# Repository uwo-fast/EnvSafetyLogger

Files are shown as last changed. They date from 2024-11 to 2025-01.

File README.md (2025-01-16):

# EnvSafetyLogger

An environmental monitoring system for industrial safety, featuring multi-gas sensors, temperature, humidity, data logging, and alerts.

This project involves designing an environmental safety monitor to measure and log air quality parameters. The monitor is housed in a custom 3D-printed enclosure and is built using a variety of sensors to measure gases and environmental conditions.

## Future Work

Future work includes:

- Weather-resistant enclosure (standard ingress protection)
- Wireless connectivity to enable data transmission and remote monitoring
- Improved calibration and integration of MQ sensors
  - See [CameronBrooks11/MQ-xx](https://github.com/CameronBrooks11/MQ-xx) for initial work involving extraction of regression parameters from component datasheets
- PCB design
- Variation for measuring closed systems with directed sampling
- Use Wet Bulb Globe Temperature (WBGT) as measure of heat stress conditions
  - WBGT is a measure of how hot it feels in direct sunlight, taking into account temperature, humidity, wind, and sun

## Results

### Schematic

The schematic shows the full circuit layout, including the Arduino Nano Every as the main controller, the various sensors, GUI components, and supporting circuitry. The schematic can be found in the `hardware` folder and is designed using KiCad.

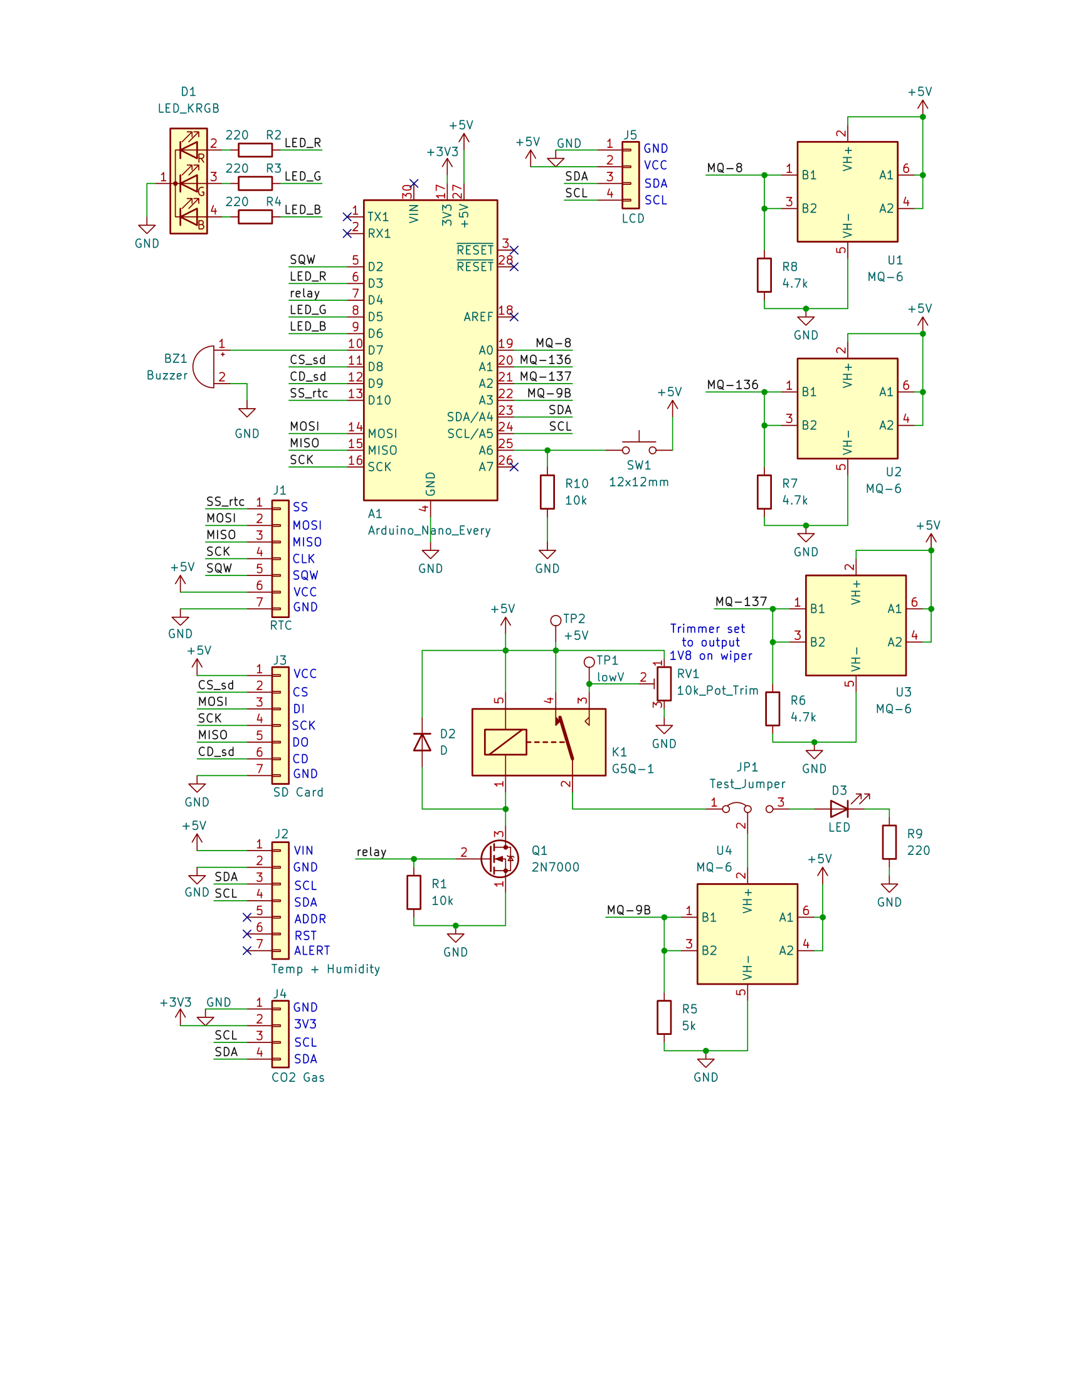
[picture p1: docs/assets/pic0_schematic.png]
Schematic


### Firmware and Hardware

The firmware for the EnvSafetyLogger is written in `.ino` format with configuration files in `.h` format, located in the `firmware` folder.

### 3D-Printed Enclosure

The enclosure was printed in PETG with a 0.8mm nozzle on a Prusa MK3S+, optimized to print without supports. The source file for the CAD design can be found [here on Onshape](https://cad.onshape.com/documents/19c4dfddea3c27460450ef2e/w/2ec8d1afb4664a197accd547/e/7aca4c51ab1e6bf835721462).

#### Fully Assembled Front View

Fully Assembled

#### Empty Enclosure

3D Printed Enclosure

### Sensor and Component Placement

This board includes the SCD41 for temperature, humidity, and carbon dioxide (CO₂); the ENS160 air quality sensor (AQI, TVOCs, eCO₂); various MQ-series gas sensors (MQ-8 for H₂, MQ-136 for H₂S, MQ-137 for NH₃, and MG-9B for CO and CH₄); and additional circuitry for driving the MQ sensor heaters, triggering audio-visual alarms, logging timestamped data, and displaying information. The board is constructed to be modular and serviceable while still being mechanically rigid and reliable, using headers and standoffs for all components.

#### Sensor Components Mounted

Sensors Populated

#### GUI and Control Panel Mounted

GUI Populated

### Soldered Boards

Two views of the soldered board showing component placement and wiring.

#### Soldered Front View

Soldered Front 1
Soldered Front 2

### Calibration and Testing

Testing and tuning were performed to ensure accurate sensor readings. The MQ9B sensor, which detects CO and CH₄, requires a bi-voltage heater cycling to operate correctly, switching between low and high voltages to improve sensitivity and response time. A trimmer pot on the board is tuned to set the relay's NO (normally open) output to 1.5V, which is used to control the heater cycle. Headers are provided to facilitate testing and allow for disconnecting the line to the MQ9B heater pin. This setup enables switching to an LED for testing without affecting the MQ9B sensor, making it easier to validate heater operation independently.

Future work will focus on establishing standard calibration procedures, including regression curve fitting of the sensor's analog signal to match the expected ppm range, and compensating this fitted curve for environmental factors such as temperature and humidity to improve accuracy.

#### Voltage Tuning

Voltage Tuning

### Installed in Environment

Once assembled, the monitor was installed and tested in a mobile photovoltaic (PV) box used for electrolysis experiments on wastewater.

Installed

### License

This project is licensed under the GNU General Public License v3.0 (GPL-3.0). See the `LICENSE` file for details.

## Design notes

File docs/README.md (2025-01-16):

# Docs

_EnvSafetyMonitor - Environmental Safety Monitoring System_

The [`assets`](assets/) folder contains images related to design and build; [`datasheets`](mq-datasheets/) contains datasheets for hardware components used in the build.

## Table of Contents

- [Docs](#docs)
  - [Table of Contents](#table-of-contents)
  - [Introduction](#introduction)
  - [System Overview](#system-overview)
  - [Hardware Components](#hardware-components)
  - [Software Dependancies](#software-dependancies)
  - [Usage Instructions](#usage-instructions)
  - [Troubleshooting](#troubleshooting)

## Introduction

EnvSafetyMonitor is an Environmental Safety Monitoring System designed to continuously monitor various environmental parameters to ensure safety and compliance. The system leverages multiple sensors to detect levels of gases, temperature, and humidity, providing real-time data visualization, logging, and alarm notifications.

## System Overview

The system integrates several components:

- **Sensors:** SCD41 (CO₂, temperature, humidity), ENS160 (AQI, TVOC, eCO₂), MQ series (H₂, H₂S, NH₃, CH₄, CO).
- **Display:** 2x16 I2C LCD for real-time data visualization.
- **Data Logging:** SD card module for recording sensor data in CSV format.
- **Alarms:** Buzzer and RGB LED indicators for alerting based on predefined thresholds.
- **User Interface:** Push button to navigate through different data screens on the LCD.

## Hardware Components

- **Arduino Nano:** The microcontroller that orchestrates all operations.
- **SCD41 Sensor:** Measures CO₂ concentration, temperature, and humidity.
- **ENS160 Sensor:** Provides Air Quality Index (AQI), Total Volatile Organic Compounds (TVOC), and equivalent CO₂ (eCO₂) readings.
- **MQ Series Sensors:**
  - **MQ-8:** Detects Hydrogen (H₂) concentrations.
  - **MQ-136:** Measures Hydrogen Sulfide (H₂S) levels.
  - **MQ-137:** Monitors Ammonia (NH₃) concentrations.
  - **MQ-9b:** Detects Methane (CH₄) and Carbon Monoxide (CO) levels.
- **2x16 I2C LCD:** Displays sensor readings and system status.
- **SD Card Module:** Logs sensor data for future analysis.
- **RGB LEDs:** Visual indicators for system status (Green for normal, Red for alarms).
- **Piezo Buzzer:** Auditory alarm for threshold breaches.
- **Relay Module:** Controls the heating element for the MQ-9b sensor.
- **Push Button:** Allows users to navigate through LCD screens.
- **RTC Module (DS3234):** Keeps accurate time for timestamping logs.

## Software Dependancies

Consult the following table for the various library dependancies.

| Dependency | Source |
| --- | --- |
| [SPI](https://www.arduino.cc/en/Reference/SPI) | Included by default in the Arduino IDE |
| [Wire](https://www.arduino.cc/en/Reference/Wire) | Included by default in the Arduino IDE |
| [EEPROM](https://www.arduino.cc/en/Reference/EEPROM) | Included by default in the Arduino IDE |
| [Math.h](https://www.arduino.cc/reference/en/language/functions/math/) | Included by default in the Arduino IDE |
| [SD](https://www.arduino.cc/en/Reference/SD) | Search `SD` in Lib Manager |
| [Rtc (Makuna)](https://github.com/Makuna/Rtc) | Search `rtc makuna` in Lib Manager |
| [SparkFun_SCD4x_Arduino_Library](https://github.com/sparkfun/SparkFun_SCD4x_Arduino_Library) | Search `SparkFun SCD4x` in Lib Manager |
| [ScioSense_ENS160](https://github.com/adafruit/ENS160_driver) | Search `Adafruit ENS160` in Lib Manager |
| [MQSensorsLib](https://github.com/miguel5612/MQSensorsLib) | Search `mqunified` in Lib Manager |
| [LiquidCrystal_I2C](https://github.com/johnrickman/LiquidCrystal_I2C) | Search `LiquidCrystal I2C Frank` in Lib Manager |
| [LiquidMenu](https://github.com/VasilKalchev/LiquidMenu) | Search `LiquidMenu` in Lib Manager |

## Usage Instructions

1. **Setup Hardware:**

   - Connect all sensors to their respective pins as defined in `config.h`.
   - Ensure the SD card is properly inserted into the SD card module.
   - Connect the RTC module to the designated chip-select pin.
   - Attach the RGB LEDs, buzzer, and relay to their respective pins.
   - Connect the push button to `A6` with appropriate pull-up/down resistors.

2. **Configure Software:**

   - Adjust settings in `config.h` as needed, such as enabling/disabling debug prints, calibration, and data logging.
   - Set appropriate threshold values for each sensor based on environmental safety requirements.

3. **Calibration:**

   - If `PERFORM_MQ_CALIBRATION` is set to `true`, calibrate the MQ sensors in clean air conditions to establish baseline readings.
   - After calibration, set `PERFORM_MQ_CALIBRATION` to `false` to use the stored R0 values from EEPROM.

4. **Running the System:**

   - Upload the `main.ino` sketch to the Arduino Nano.
   - Upon startup, the system initializes all components and begins monitoring.
   - Navigate through different sensor data screens using the push button.
   - Monitor alarms via the buzzer and RGB LED indicators.

5. **Data Access:**
   - Retrieve the `dataLog.csv` file from the SD card for analysis using spreadsheet software or other data processing tools.
   - Real-time data can be viewed via Serial Monitor if enabled.

## Troubleshooting

- **SD Card Initialization Failed:**

  - Ensure the SD card is properly inserted.
  - Verify the chip-select pin is correctly connected.
  - Check the SD card format (should be FAT16/FAT32).

- **RTC Lost Confidence in DateTime:**

  - Check RTC module connections.
  - Ensure the RTC has a backup battery for maintaining time.

- **Sensor Not Detected:**

  - Verify wiring connections for each sensor.
  - Ensure sensors are powered correctly.
  - Check for I2C address conflicts.

- **Alarms Not Triggering:**

  - Confirm that sensor readings exceed the set thresholds.
  - Ensure the buzzer and LED pins are correctly connected and functioning.

- **LCD Not Displaying Data:**
  - Ensure the LiquidMenu library is correctly configured
    - Ensure you have modified the LiquidMenu library header to use the I2C library
    - Ensure the I2C LCD library is also installed and included in the project
  - Verify I2C connections.
  - Check the LCD address and dimensions in `config.h`.

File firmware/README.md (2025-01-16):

# Firmware Docs

Welcome to the firmware docs! Here you will find...fuinish

## Software Structure

The software is divided into four main files:`main.ino`, `config.h`, `mqGas.h` and `alarmThresholds.h`.

### `main.ino`

The program monitors environmental safety parameters using various sensors and logs data to an SD card and serial output.

#### Program Flow

1. Initialize pins, sensors, and libraries
2. Read sensor data every `SAMPLING_INTERVAL_MS`
3. Update LCD menu display and check/triggers alarms
4. Log data to SD card and serial output

#### Key Components

- **Sensor Initialization and Calibration**:
  - SCD41: Begins periodic measurement upon successful initialization
  - ENS160: Configured to operate in standard mode
  - MQ Series: Calibrated using `PERFORM_MQ_CALIBRATION` flag, analog values mapped to ppm using exponential regression, R0 value stored in EEPROM
- **Alarm System**:
  - Threshold-based alarm triggering (DANGER/WARNING)
  - Activates piezo buzzer and changes RGB LED color to red upon alarm
- **Logging**:
  - SD card (CSV): Records sensor data with timestamp
  - Serial output (JSON): Real-time monitoring or integration with other systems
- **LCD Menu Interface**:
  - Utilizes LiquidMenu library for multiple screens displaying sensor readings
  - Navigation via push button, with screens for system title, timestamp, and individual sensor readings

### `config.h`

This header file contains all configurable settings, pin definitions, thresholds, and other constants used throughout the EnvSafetyMonitor system.

- Debugging Settings
  - `ENABLE_DEBUG_PRINTS`: Toggle for enabling/disabling debug messages.
  - `ENABLE_DATA_PRINTS`: Toggle for enabling/disabling data output to Serial.
- Calibration Settings
  - `PERFORM_MQ_CALIBRATION`: Determines whether to calibrate MQ sensors on startup. Note that once this is enabled you should boot the system, allow calibration, then reupload with this setting disabled during production use.
- Logging Settings
  - `LOG_FILE_NAME`: Name of the CSV log file on the SD card.
  - `LOG_TO_SD`: Enables/disables logging sensor data to the SD card.
- Standard Colors Definitions
  - `RED`: RGB values for red color.
  - `GREEN`: RGB values for green color.
- Sampling Settings
  - `SAMPLING_INTERVAL_MS`: Time interval between consecutive sensor readings.
- I2C LCD Settings
  - `LCD_I2C_ADDRESS`: I2C address of the LCD.
  - `LCD_COLUMNS`: Number of columns on the LCD.
  - `LCD_ROWS`: Number of rows on the LCD.
- Serial Communication Settings
  - `SERIAL_BAUD_RATE`: Baud rate for Serial communication.
- Debounce Settings
  - `DEBOUNCE_DELAY_MS`: Delay for debouncing the push button.

### `alarmThresholds.h`

The following thresholds are used to trigger warning and danger alarms for various environmental parameters.

#### Temperature & Humidity Thresholds

- Temperature
  - `TEMP_WARNING_THRESHOLD_C`: 30.0°C - Temperature warning threshold
  - `TEMP_DANGER_THRESHOLD_C`: 35.0°C - Temperature danger threshold
  - Temperatures around 30°C increase the risk of heat stress, while temperatures at or above 35°C pose a higher risk of heat-related illnesses.
- Relative Humidity (RH)
  - `HUMIDITY_WARNING_THRESHOLD_RH`: 60.0%RH - Humidity warning threshold
  - `HUMIDITY_DANGER_THRESHOLD_RH`: 80.0%RH - Humidity danger threshold
    High humidity levels reduce the body's ability to cool itself, with increased risk at 80% humidity.

#### Gas Concentration Thresholds

- Carbon Dioxide (CO2)

  - `CO2_WARNING_THRESHOLD_PPM`: 5000 ppm - CO₂ warning threshold
  - `CO2_DANGER_THRESHOLD_PPM`: 15000 ppm - CO₂ danger threshold
  - **Based on:** OSHA's PEL for CO₂ is 5,000 ppm over an 8-hour workday, with concentrations above 15,000 ppm causing respiratory issues.

- Hydrogen (H2)

  - `H2_WARNING_THRESHOLD_PPM`: 4000 ppm - H₂ warning threshold
  - `H2_DANGER_THRESHOLD_PPM`: 8000 ppm - H₂ danger threshold
  - **Based on:** Hydrogen is highly flammable, with warning and danger thresholds set at 10% and 20% of the Lower Explosive Limit (LEL).

- Hydrogen Sulfide (H2S)

  - `H2S_WARNING_THRESHOLD_PPM`: 10 ppm - H₂S warning threshold
  - `H2S_DANGER_THRESHOLD_PPM`: 50 ppm - H₂S danger threshold
  - **Based on:** OSHA's PEL for H₂S is 10 ppm over an 8-hour workday, with concentrations above 15 ppm causing eye irritation.

- Ammonia (NH3)

  - `NH3_WARNING_THRESHOLD_PPM`: 25 ppm - NH₃ warning threshold
  - `NH3_DANGER_THRESHOLD_PPM`: 50 ppm - NH₃ danger threshold
  - **Based on:** OSHA's PEL for ammonia is 50 ppm and 25 ppm over an 8-hour workday, with levels above 50 ppm causing eye and respiratory irritation.

- Methane (CH4)

  - `CH4_WARNING_THRESHOLD_PPM`: 5000 ppm - CH₄ warning threshold
  - `CH4_DANGER_THRESHOLD_PPM`: 10000 ppm - CH₄ danger threshold
  - **Based on:** Methane is flammable, with warning and danger thresholds set at 10% and 20% of the Lower Explosive Limit (LEL).

- Carbon Monoxide (CO)
  - `CO_WARNING_THRESHOLD_PPM`: 35 ppm - CO warning threshold
  - `CO_DANGER_THRESHOLD_PPM`: 50 ppm - CO danger threshold
  - **Based on:** OSHA's PEL for CO is 50 ppm and 25 ppm over an 8-hour workday, with levels above 50 ppm causing headaches and dizziness.

### `mqgas.h`

The MQ gas sensors detect specific gases by measuring the change in their internal resistance when exposed to different gas concentrations. The resistance value (`RS`) changes in proportion to the gas concentration, allowing for the calculation of the gas's parts per million (ppm) level.

#### Regression Formula

The MQ sensors use a logarithmic formula to relate the sensor resistance ratio (`RS / R0`) to gas concentration:

```c
ppm = a * (RS / R0)^b
```

where:

- a and b are constants specific to each sensor and gas, derived from calibration and datasheet values.
- RS is the sensor resistance in the current environment.
- R0 is the baseline resistance of the sensor in clean air, obtained through calibration.

#### Sensor Resistance (RS) Calculation

RS is calculated from the sensor's analog voltage reading as follows:

```c
RS = ((V_supply - V_sensor) \* RL) / V_sensor
```

where:

- V_sensor is the voltage at the sensor’s output.
- V_supply is the supply voltage to the sensor.
- RL is the load resistance in series with the sensor.

#### Baseline Resistance (R0) Calibration

R0 represents the sensor’s resistance in a known clean air environment and is used as a baseline for gas concentration calculations. During calibration:

- The sensor's RS is measured in clean air.
- R0 is calculated as the average RS in this environment and is saved in EEPROM to maintain consistency across power cycles.

#### Clean Air Ratio

The clean air ratio (RS / R0 in clean air) is a reference value specific to each sensor. This ratio helps establish the baseline resistance and is used during R0 calibration.

#### Sensor Definitions

- **MQ-8 Sensor (Hydrogen, H₂)**

  - `MQ8_TYPE`: "MQ-8"
  - `MQ8_RATIO_CLEAN_AIR`: 70
  - `A_VALUE_MQ8`: 71.7592
  - `B_VALUE_MQ8`: -0.9760
  - `EEPROM_ADDRESS_MQ8_R0`: 0

- **MQ-136 Sensor (Hydrogen Sulfide, H₂S)**

  - `MQ136_TYPE`: "MQ-136"
  - `MQ136_RATIO_CLEAN_AIR`: 3.6
  - `A_VALUE_MQ136`: 1.0715
  - `B_VALUE_MQ136`: -0.8877
  - `EEPROM_ADDRESS_MQ136_R0`: 4

- **MQ-137 Sensor (Ammonia, NH₃)**

  - `MQ137_TYPE`: "MQ-137"
  - `MQ137_RATIO_CLEAN_AIR`: 4.2
  - `A_VALUE_MQ137`: 1.0613
  - `B_VALUE_MQ137`: -0.8905
  - `EEPROM_ADDRESS_MQ137_R0`: 8

- **MQ-9b Sensor (Carbon Monoxide, CO & Methane, CH₄)**
  - `MQ9B_TYPE`: "MQ-9"
  - `MQ9B_RATIO_CLEAN_AIR`: 9.6
  - `A_VALUE_MQ9B_CH4`: 4.9059
  - `B_VALUE_MQ9B_CH4`: -0.6699
  - `A_VALUE_MQ9B_CO`: 4.8726
  - `B_VALUE_MQ9B_CO`: -0.6989
  - `EEPROM_ADDRESS_MQ9B_R0`: 12
  - `SETTLE_TIME_TO_CO`: 20000 ms
  - `SETTLE_TIME_TO_CH4`: 10000 ms

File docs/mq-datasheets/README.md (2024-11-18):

# MQ Gas Sensors Overview

MQ gas sensors, such as the MQ-8, are low-cost, widely used sensors that detect various gases by measuring the change in conductivity of a SnO2-sensitive material in response to gas concentration. This change in conductivity can be interpreted as a resistance change (Rs), which increases or decreases depending on the target gas.

## Sensor Operation and Calibration

1. **Structure and Operation**:
   - MQ sensors consist of a heating element and a SnO2-sensitive layer. The sensor requires two voltage inputs: a heater voltage (VH) to maintain the sensor's optimal temperature and a circuit voltage (VC) for measurement.
   - In clean air, the sensor's resistance (Rs) is at a baseline level, and the sensor outputs a corresponding voltage (VRL) across an external load resistor (RL). When exposed to a target gas, the conductivity increases, causing Rs to change based on the gas concentration.

2. **Calibration**:
   - Each sensor requires calibration to determine its baseline resistance, R0, which represents the resistance in clean air. Calibration steps:
     - Expose the sensor to clean air and measure Rs.
     - Calculate R0 using the clean air ratio, a predefined constant (e.g., MQ-8 clean air ratio is 70), as follows:
       R0 = Rs / Clean Air Ratio
   - This value of R0 is unique to each sensor and serves as a reference for future measurements.

3. **Using R0 for Gas Measurement**:
   - During operation, Rs is measured in the presence of the target gas, and the Rs/R0 ratio is calculated. This ratio can be used with a regression equation derived from the sensor’s datasheet to estimate gas concentration (PPM).
   - The general form of the regression equation is:
     PPM = A * (Rs / R0) ^ B
     where A and B are gas-specific constants provided by the datasheet or determined experimentally.

4. **Typical Sensitivity and Environment Effects**:
   - MQ sensors are sensitive to various gases, but their sensitivity varies depending on the gas. For example, the MQ-8 is primarily sensitive to hydrogen but also responds to gases like methane (CH4) and carbon monoxide (CO) to a lesser extent.
   - Temperature and humidity changes can affect Rs, so periodic recalibration or compensation may be necessary for consistent results, especially in variable environments.

## Important Parameters

- **Clean Air Ratio**: A predefined constant that indicates the expected Rs/R0 ratio in clean air.
- **R0**: The baseline sensor resistance in clean air, determined during calibration.
- **Rs**: The sensor resistance measured in the presence of a target gas.
- **A and B Constants**: Regression constants used to calculate gas concentration based on Rs/R0.

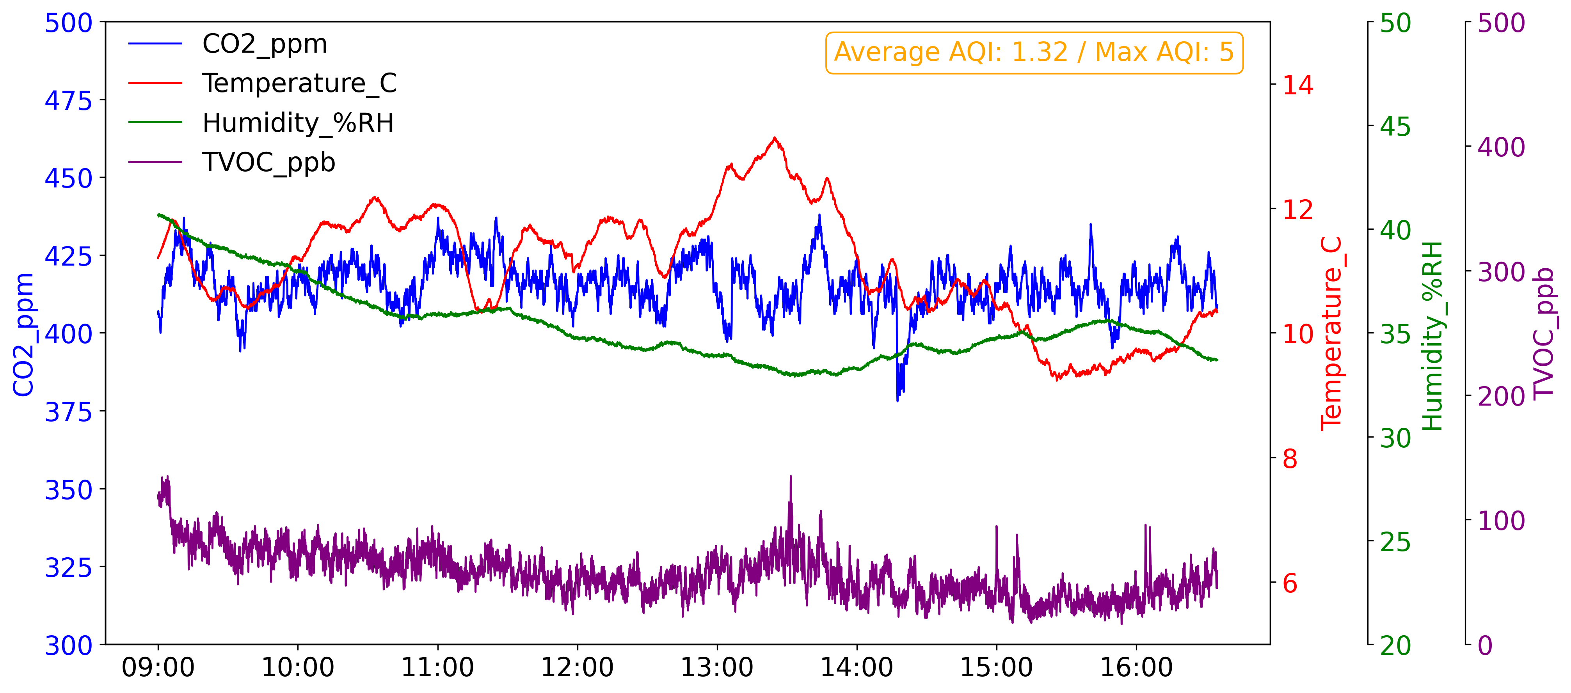
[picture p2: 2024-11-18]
docs/data_analysis_11072024/environment_data_notitle.png

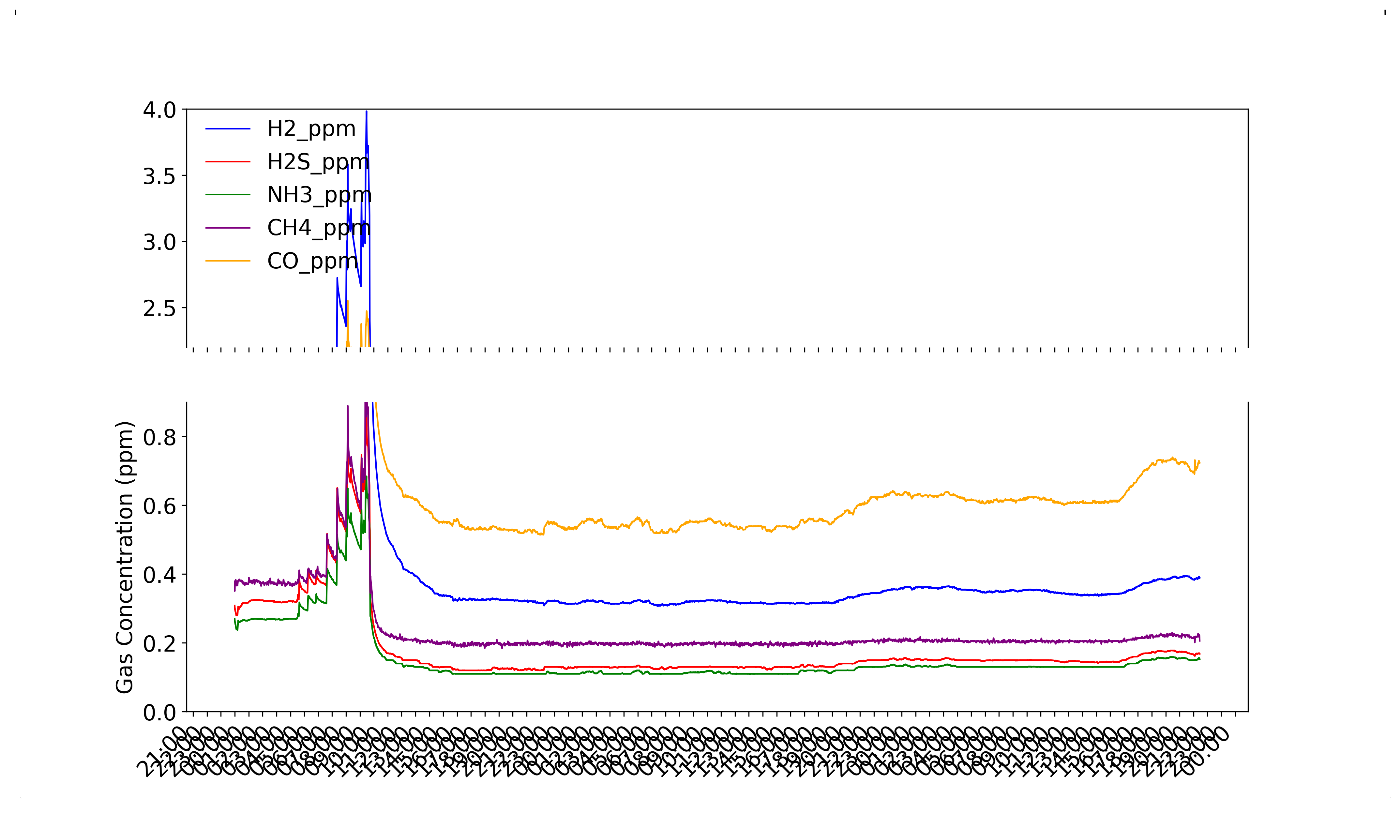
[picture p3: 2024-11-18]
docs/data_analysis_11072024/newData/gas_concentrations_smoothed_notitle3.png

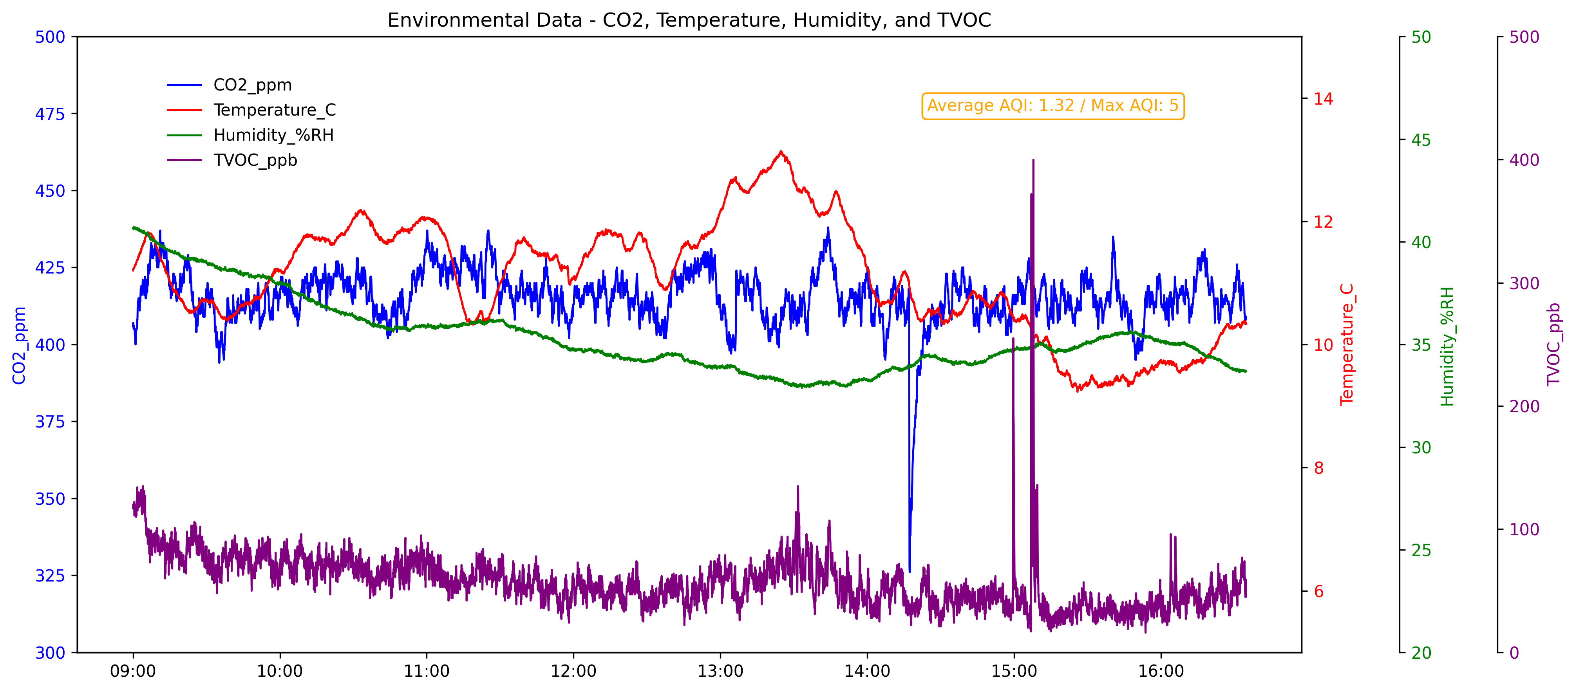
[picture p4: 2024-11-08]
docs/data_analysis_11072024/environment_data.png

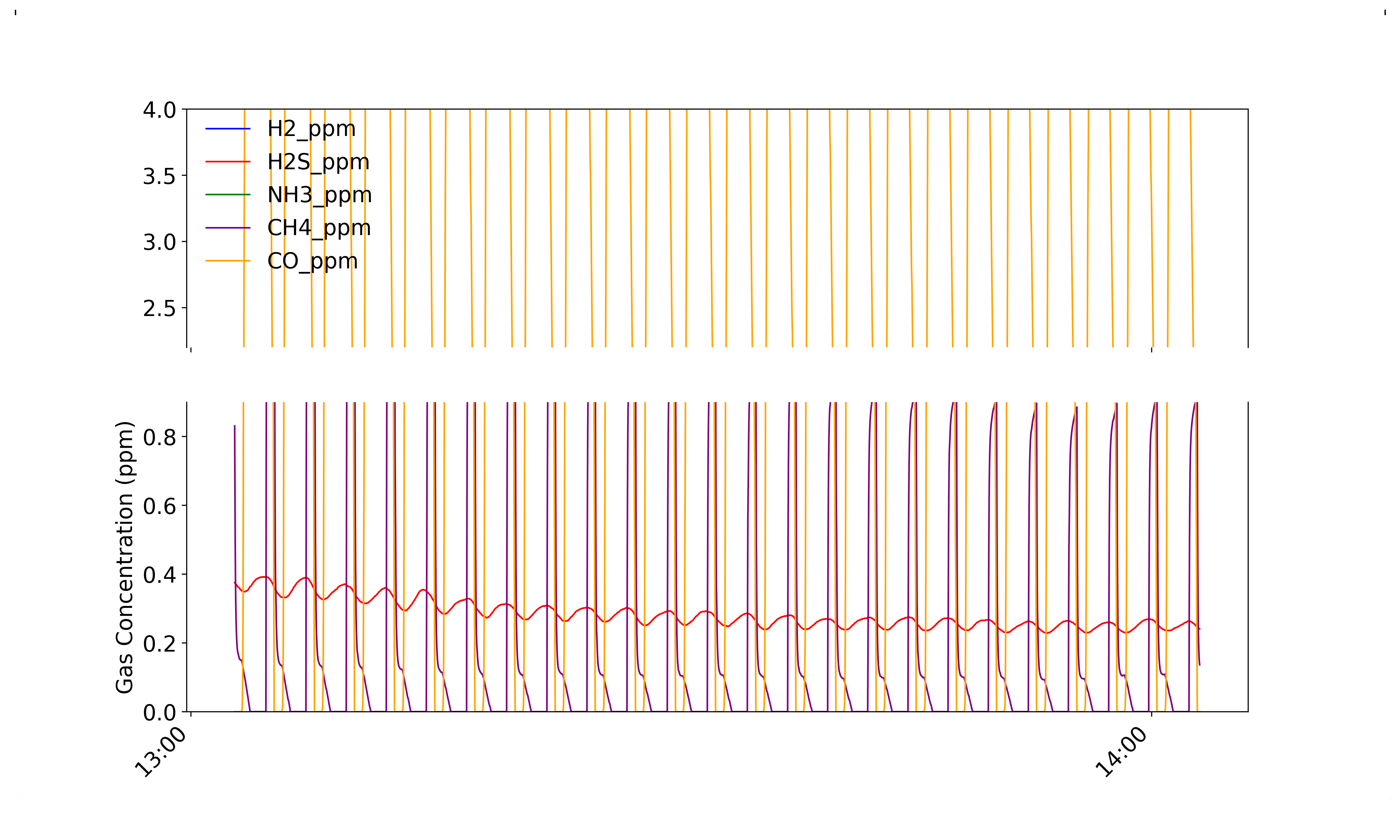
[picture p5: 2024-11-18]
docs/data_analysis_11072024/gas_concentrations_smoothed_notitle.png

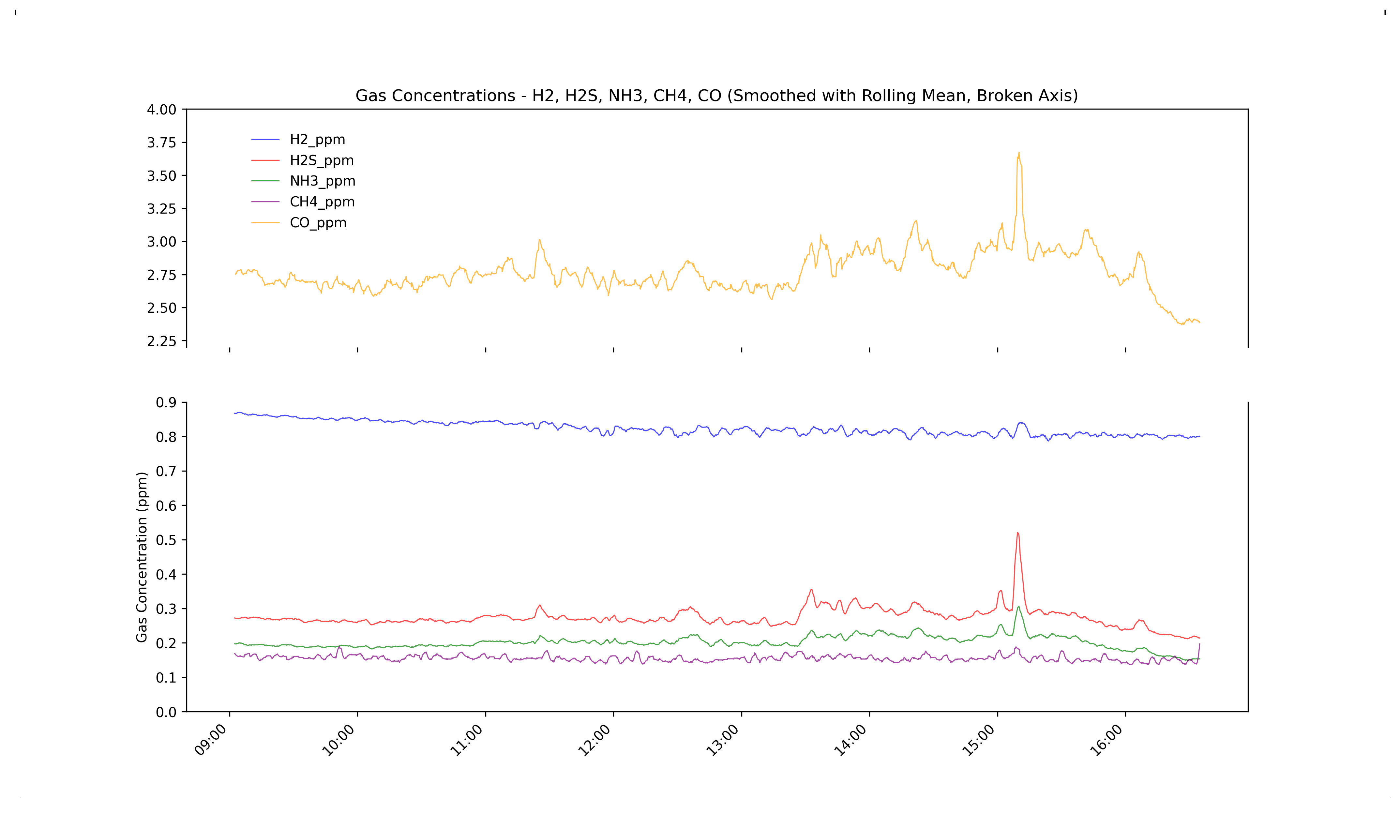
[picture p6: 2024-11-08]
docs/data_analysis_11072024/gas_concentrations_smoothed.png

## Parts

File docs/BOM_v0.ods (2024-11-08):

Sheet: Sheet1
Name | Description | Quantity | Cost | Link | Notes
Arduino Nano Every | Controller | 1 |  | mouser
Sparkfun dead on DS3231 |  | 1 |  | sparkfun
Sparkfun Level Shifting MicroSD |  | 1 |  | sparkfun
32GB Micro SD |  | 1
CO2 sensor sparkfun SCD41 |  | 1 |  | sparkfun
Adafruit ENS160 |  | 1 |  | adafruit
MQ-8 |  | 1 |  | sparkfun
MQ-136 |  | 1 |  | sparkfun
MQ-137 |  | 1 |  | sparkfun
MQ-9B |  | 1 |  | sparkfun
MQ Breakout |  | 4 |  | sparkfun
5mm RGB common cathode LED |  | 1
5mm LED |  | 1
Piezo Buzzer 5v |  | 1
Push button |  | 1
LCD I2C 2x16 |  | 1 |  | amazon sunfounder i2c lcd
10k Trim Pot |  | 1
5k Resistor |  | 4
220 Resistor |  | 4
mosfet 2n7000 |  | 1
10k Resistor |  | 2
1n4148 Diode

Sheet: Sheet2
Part # | Name | Quantity | Cost (CAD) | Total Cost (CAD) | Link | Notes
1 | Arduino Nano Every | 1.00 | $17.99 | $17.99 | https://www.canadarobotix.com/products/2495 | Bigger memory than classic Nano with 328P, available in Canada
2 | SparkFun DeadOn RTC Breakout - DS3234 | 1.00 | $34.09 | $34.09 | https://www.sparkfun.com/products/10160 | Accurate SPI RTC
3 | SparkFun Level Shifting microSD Breakout | 1.00 | $8.28 | $8.28 | https://www.sparkfun.com/products/13743 | Handles 3.3V/5V logic levels
4 | 32GB MicroSD Card | 1.00 | $12.99 | $12.99 | https://a.co/d/8i0q3gs | Compatible with microSD module
5 | 3V CR2032 Coin Cell | 0.10 | $13.43 | $1.34 | https://a.co/d/bcWUG2P | For RTC backup
6 | SparkFun SCD41 CO₂ Sensor | 1.00 | $90.38 | $90.38 | https://www.sparkfun.com/products/22396 | High-accuracy CO₂ measurement and temp + humidity
7 | Adafruit ENS160 | 1.00 | $30.54 | $30.54 | https://www.adafruit.com/product/5606 | Multi-parameter air quality for AQI, TVOC, eCO2
8 | MQ-8 Hydrogen Sensor | 1.00 | $7.65 | $7.65 | https://www.sparkfun.com/products/10916 | Requires breakout board
9 | MQ-136 Hydrogen Sulfide Sensor | 1.00 | $52.18 | $52.18 | https://www.sparkfun.com/products/17052 | Requires breakout board
10 | MQ-137 Ammonia Sensor | 1.00 | $52.18 | $52.18 | https://www.sparkfun.com/products/17053 | Requires breakout board
11 | MQ-9B CO & Methane Sensor | 1.00 | $9.04 | $9.04 | https://www.sparkfun.com/products/17050 | Requires breakout board
12 | SparkFun Gas Sensor Breakout | 4.00 | $1.46 | $5.84 | https://www.sparkfun.com/products/8891 | One per MQ sensor
13 | 5mm RGB LED | 1.00 | $2.97 | $2.97 | https://www.mouser.ca/ProductDetail/SparkFun/COM-16911 | Common cathode
14 | 5mm LED | 1.00 | $0.77 | $0.77 | https://www.mouser.ca/ProductDetail/Vishay-Siliconix/TLHG6420-CSZ | Specify color as needed
15 | Piezo Buzzer 5V | 1.00 | $1.32 | $1.32 | https://www.mouser.ca/ProductDetail/Same-Sky/CMI-0955-05TH | 5V, 12mm size
16 | SPDT Relay | 1.00 | $2.32 | $2.32 | https://www.mouser.ca/ProductDetail/Omron-Electronics/G5Q-1-DC5 | 5V coil, SPDT
17 | Push Button | 0.01 | $10.29 | $0.10 | https://a.co/d/fO4Napx | Pack of 100
18 | LCD I2C 2x16 | 1.00 | $13.59 | $13.59 | https://a.co/d/aVtHvKR | 2x16 I2C display for GUI
19 | 10k Trim Pot | 0.10 | $17.74 | $1.77 | https://a.co/d/fv0iEl8 | Pack of 10
20 | 2N7000 MOSFET | 1.00 | $0.80 | $0.80 | https://www.mouser.ca/ProductDetail/onsemi-Fairchild/2N7000 | Drives relay coil
21 | 1N4148 Diode | 1.00 | $0.15 | $0.15 | https://www.mouser.ca/ProductDetail/onsemi-Fairchild/1N4148 | Across relay coil
22 | Resistors Assortment | 0.02 | $15.99 | $0.30 | https://a.co/d/5KeYhGB | Includes 4.7k, 10k, 220Ω values
23 | Protoboard 10x15cm | 0.33 | $15.99 | $5.33 | https://a.co/d/h1yTpQO | For circuit assembly
24 | 24 AWG Hookup Wire | 0.06 | $21.99 | $1.22 | https://a.co/d/bu35DZB | For connections
25 | M3 Nylon Standoffs | 0.06 | $16.48 | $1.03 | https://a.co/d/g6Q9Fwy | For mounting
26 | 2.54mm Female Headers | 0.08 | $18.94 | $1.58 | https://a.co/d/2CcMMEq | For connections
 |  |  |  | $355.76

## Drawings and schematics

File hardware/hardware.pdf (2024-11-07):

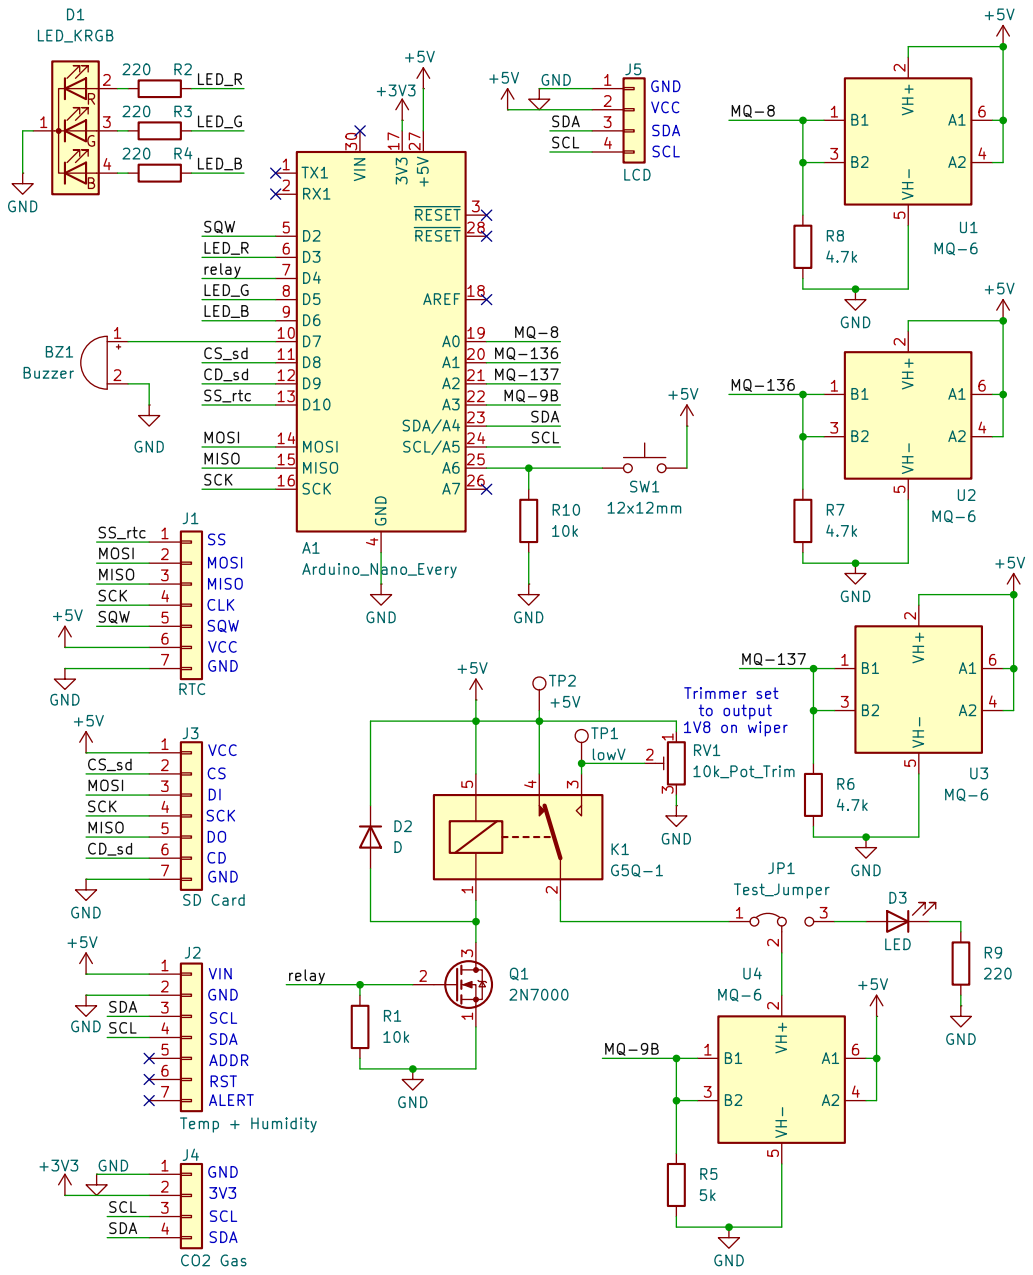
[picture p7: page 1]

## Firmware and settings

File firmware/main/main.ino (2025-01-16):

/***************************************************************************
  EnvSafetyMonitor - Environmental Safety Monitoring System

  This program monitors environmental parameters using SCD41, ENS160, MQ-8, MQ-136, MQ-137,
  and MQ-9b sensors, displays data on a 2x16 I2C LCD, logs data to an SD card
  in CSV format, and triggers alarms based on threshold values. The LCD menu allows
  scrolling through different parameter screens using a push button.

***************************************************************************/

// Include Core Arduino Library
#include <Arduino.h>

// Program Specific Configurations
#include "config.h"
#include "mqGas.h"
#include "alarmThresholds.h"

// Standard Arduino Libraries
#include <SPI.h>    // SPI library
#include <Wire.h>   // I2C library
#include <EEPROM.h> // EEPROM library
#include <math.h>   // For NAN and isnan()

// Logging Libraries
#include <SD.h>        // SD card library
#include <RtcDS3234.h> // RTC library

// Sensor Libraries
#include "SparkFun_SCD4x_Arduino_Library.h" // SCD41 Library
#include <ScioSense_ENS160.h>               // ENS160 library
#include <MQUnifiedsensor.h>                // MQ sensor library

// LCD Libraries
#include <LiquidCrystal_I2C.h> // Base I2C LCD library
#include <LiquidMenu.h>       // LCD Menu library

// Initialize LCD
LiquidCrystal_I2C lcd(LCD_I2C_ADDRESS, LCD_COLUMNS, LCD_ROWS);

// Initialize LiquidMenu
LiquidMenu menu(lcd);

// Initialize RTC
RtcDS3234<SPIClass> Rtc(SPI, DS3234_CS_PIN);

// Initialize SCD41 Sensor
SCD4x scd41;

// Initialize ENS160 Sensor
ScioSense_ENS160 ens160(ENS160_I2CADDR_1);

// Initialize the MQ Sensors
MQUnifiedsensor MQ8(DEVICE, VOLTAGE_RESOLUTION, ADC_BIT_RESOLUTION, mq8Pin, MQ8_TYPE);
MQUnifiedsensor MQ136(DEVICE, VOLTAGE_RESOLUTION, ADC_BIT_RESOLUTION, mq136Pin, MQ136_TYPE);
MQUnifiedsensor MQ137(DEVICE, VOLTAGE_RESOLUTION, ADC_BIT_RESOLUTION, mq137Pin, MQ137_TYPE);
MQUnifiedsensor MQ9B(DEVICE, VOLTAGE_RESOLUTION, ADC_BIT_RESOLUTION, mq9bPin, MQ9B_TYPE);

// Enum for Alarm Levels
enum AlarmLevel
{
    NO_ALARM,
    WARNING,
    DANGER
};

// Global Variables
File dataFile;

// Sensor Values from SCD41
int co2 = 0;
float temperature = 0.0;
float humidity = 0.0;
char timestamp[20]; // Use a character array for timestamp

// Sensor Values from ENS160
int aqi = 0;
int tvoc = 0;
int eco2 = 0;

// Sensor Values from MQ Sensors
float h2_ppm = 0.0;
float h2s_ppm = 0.0;
float nh3_ppm = 0.0;
float ch4_ppm = 0.0; // Methane concentration
float co_ppm = 0.0;  // Carbon Monoxide concentration

// Button Debounce Variables
bool buttonState = HIGH;
bool lastButtonState = HIGH;
unsigned long lastDebounceTime = 0;

// Alarm Variables
AlarmLevel alarmLevel = NO_ALARM;
unsigned long lastBuzzerToggleTime = 0;
bool buzzerState = false;
const unsigned long BUZZER_TOGGLE_INTERVAL_MS = 1000; // 1 second

// MQ-9b Relay Control Variables
unsigned long mq9bPreviousMillis = 0;
unsigned long mq9bInterval = 60000; // 60 seconds for HIGH (5V) phase
bool mq9bHighState = true;          // Start in the HIGH (5V) phase
unsigned long mq9bSwitchTime = 0;   // Time when MQ-9b relay was switched

// Timing Variable for Sensor Sampling
unsigned long lastMillis = 0; // Declared globally

// Function Declarations
void initializePins();
void initializeAlarms();
void initializeLCDMenu();
void logSensorData();
void checkAndTriggerAlarms();
void updateLCDMenu();
void handleButtonPress();
void controlMQ9bRelay();
void readSensors();

// Create LiquidLine and LiquidScreen objects

// Screen 0: Title and Timestamp
LiquidLine screen0_line1(0, 0, "EnvSafetyMonitor");
LiquidLine screen0_line2(0, 1, timestamp);
LiquidScreen screen0(screen0_line1, screen0_line2);

// Screen1: CO2 ppm
LiquidLine screen1_line1(0, 0, "CO2 ppm:");
LiquidLine screen1_line2(0, 1, co2, "ppm");
LiquidScreen screen1(screen1_line1, screen1_line2);

// Screen2: Temperature C
LiquidLine screen2_line1(0, 0, "Temp C:");
LiquidLine screen2_line2(0, 1, temperature, "C");
LiquidScreen screen2(screen2_line1, screen2_line2);

// Screen3: Humidity %RH
LiquidLine screen3_line1(0, 0, "Humidity:");
LiquidLine screen3_line2(0, 1, humidity, "%RH");
LiquidScreen screen3(screen3_line1, screen3_line2);

// Screen4: AQI
LiquidLine screen4_line1(0, 0, "AQI:");
LiquidLine screen4_line2(0, 1, aqi, "");
LiquidScreen screen4(screen4_line1, screen4_line2);

// Screen5: TVOC ppb
LiquidLine screen5_line1(0, 0, "TVOC ppb:");
LiquidLine screen5_line2(0, 1, tvoc, "ppb");
LiquidScreen screen5(screen5_line1, screen5_line2);

// Screen6: eCO2 ppm
LiquidLine screen6_line1(0, 0, "eCO2 ppm:");
LiquidLine screen6_line2(0, 1, eco2, "ppm");
LiquidScreen screen6(screen6_line1, screen6_line2);

// Screen7: H2 ppm
LiquidLine screen7_line1(0, 0, "H2 ppm:");
LiquidLine screen7_line2(0, 1, h2_ppm, "ppm");
LiquidScreen screen7(screen7_line1, screen7_line2);

// Screen8: H2S ppm
LiquidLine screen8_line1(0, 0, "H2S ppm:");
LiquidLine screen8_line2(0, 1, h2s_ppm, "ppm");
LiquidScreen screen8(screen8_line1, screen8_line2);

// Screen9: NH3 ppm
LiquidLine screen9_line1(0, 0, "NH3 ppm:");
LiquidLine screen9_line2(0, 1, nh3_ppm, "ppm");
LiquidScreen screen9(screen9_line1, screen9_line2);

// Screen10: CH4 ppm
LiquidLine screen10_line1(0, 0, "CH4 ppm:");
LiquidLine screen10_line2(0, 1, ch4_ppm, "ppm");
LiquidScreen screen10(screen10_line1, screen10_line2);

// Screen11: CO ppm
LiquidLine screen11_line1(0, 0, "CO ppm:");
LiquidLine screen11_line2(0, 1, co_ppm, "ppm");
LiquidScreen screen11(screen11_line1, screen11_line2);

void setup()
{
    Serial.begin(SERIAL_BAUD_RATE);
    while (!Serial && ENABLE_DATA_PRINTS)
        ; // Wait for serial if data printing is enabled

    initializePins();

    // Initialize I2C
    Wire.begin();

    // Initialize SD card
    if (LOG_TO_SD)
    {
        if (!SD.begin(chipSelect))
        {
#if ENABLE_DEBUG_PRINTS
            Serial.println(F("SD Card initialization failed!"));
#endif
            while (true)
                ; // Halt if SD card fails to initialize
        }
#if ENABLE_DEBUG_PRINTS
        Serial.println(F("SD Card initialized."));
#endif

        // Check if the log file exists
        if (!SD.exists(LOG_FILE_NAME))
        {
            // Create the file and write the header
            dataFile = SD.open(LOG_FILE_NAME, FILE_WRITE);
            if (dataFile)
            {
                // Write CSV header
                dataFile.println("Timestamp,CO2_ppm,Temperature_C,Humidity_%RH,AQI,TVOC_ppb,eCO2_ppm,H2_ppm,H2S_ppm,NH3_ppm,CH4_ppm,CO_ppm");
                dataFile.close();
#if ENABLE_DEBUG_PRINTS
                Serial.println(F("CSV Header written to SD Card."));
#endif
            }
            else
            {
#if ENABLE_DEBUG_PRINTS
                Serial.println(F("Error creating log file on SD Card."));
#endif
            }
        }
    }

    // Initialize RTC
    SPI.begin();
    Rtc.Begin();

    RtcDateTime compiled = RtcDateTime(__DATE__, __TIME__);
    if (!Rtc.IsDateTimeValid())
    {
#if ENABLE_DEBUG_PRINTS
        Serial.println(F("RTC lost confidence in the DateTime!"));
#endif
        Rtc.SetDateTime(compiled);
    }

    if (!Rtc.GetIsRunning())
    {
#if ENABLE_DEBUG_PRINTS
        Serial.println(F("RTC was not actively running, starting now"));
#endif
        Rtc.SetIsRunning(true);
    }

    Rtc.Enable32kHzPin(false);
    Rtc.SetSquareWavePin(DS3234SquareWavePin_ModeNone);

    // Initialize SCD41 sensor
    if (!scd41.begin())
    {
        Serial.println(F("SCD41 sensor not detected. Check wiring."));
        while (true)
            ; // Halt if SCD41 fails to initialize
    }
#if ENABLE_DEBUG_PRINTS
    Serial.println(F("SCD41 initialized."));
#endif
    scd41.startPeriodicMeasurement();
    delay(100); // Short delay after SCD41 initialization to avoid I2C conflict

    // Initialize ENS160 sensor
    Serial.print(F("ENS160..."));
    ens160.begin();
    Serial.println(ens160.available() ? F("done.") : F("failed!"));
    if (ens160.available())
    {
#if ENABLE_DEBUG_PRINTS
        Serial.print(F("\tRev: "));
        Serial.print(ens160.getMajorRev());
        Serial.print(F("."));
        Serial.print(ens160.getMinorRev());
        Serial.print(F("."));
        Serial.println(ens160.getBuild());
#endif

        Serial.print(F("\tStandard mode "));
        Serial.println(ens160.setMode(ENS160_OPMODE_STD) ? F("done.") : F("failed!"));
    }

    // Initialize MQ-8 Sensor
    MQ8.setRegressionMethod(1); // _PPM =  a*ratio^b
    MQ8.setA(A_VALUE_MQ8);
    MQ8.setB(B_VALUE_MQ8); // Configure the equation to calculate H2 concentration

    MQ8.init();

    if (PERFORM_MQ_CALIBRATION)
    {
#if ENABLE_DEBUG_PRINTS
        Serial.print("Calibrating MQ-8, please wait.");
#endif
        float calcR0 = 0;
        for (int i = 1; i <= 10; i++)
        {
            MQ8.update(); // Read the voltage from the analog pin
            calcR0 += MQ8.calibrate(MQ8_RATIO_CLEAN_AIR);
#if ENABLE_DEBUG_PRINTS
            Serial.print(".");
#endif
        }
        float mq8_r0 = calcR0 / 10;
        MQ8.setR0(mq8_r0);
#if ENABLE_DEBUG_PRINTS
        Serial.println(" done!");
#endif

        if (isinf(calcR0))
        {
            Serial.println("Warning: Connection issue, MQ-8 R0 is infinite (Open circuit detected). Please check your wiring and supply.");
            while (1)
                ;
        }
        if (calcR0 == 0)
        {
            Serial.println("Warning: Connection issue found, MQ-8 R0 is zero (Analog pin shorts to ground). Please check your wiring and supply.");
            while (1)
                ;
        }
        // Save R0 to EEPROM
        EEPROM.put(EEPROM_ADDRESS_MQ8_R0, mq8_r0);
    }
    else
    {
        // Load R0 from EEPROM
        float mq8_r0 = 0.0;
        EEPROM.get(EEPROM_ADDRESS_MQ8_R0, mq8_r0);
        MQ8.setR0(mq8_r0);
    }
    MQ8.serialDebug(ENABLE_DEBUG_PRINTS);

    // Initialize MQ-136 Sensor
    MQ136.setRegressionMethod(1); // _PPM =  a*ratio^b
    MQ136.setA(A_VALUE_MQ136);
    MQ136.setB(B_VALUE_MQ136); // Configure the equation to calculate H2S concentration

    MQ136.init();

    if (PERFORM_MQ_CALIBRATION)
    {
#if ENABLE_DEBUG_PRINTS
        Serial.print("Calibrating MQ-136, please wait.");
#endif
        float calcR0 = 0;
        for (int i = 1; i <= 10; i++)
        {
            MQ136.update(); // Read the voltage from the analog pin
            calcR0 += MQ136.calibrate(MQ136_RATIO_CLEAN_AIR);
#if ENABLE_DEBUG_PRINTS
            Serial.print(".");
#endif
        }
        float mq136_r0 = calcR0 / 10;
        MQ136.setR0(mq136_r0);
#if ENABLE_DEBUG_PRINTS
        Serial.println(" done!");
#endif

        if (isinf(calcR0))
        {
            Serial.println("Warning: Connection issue, MQ-136 R0 is infinite (Open circuit detected). Please check your wiring and supply.");
            while (1)
                ;
        }
        if (calcR0 == 0)
        {
            Serial.println("Warning: Connection issue found, MQ-136 R0 is zero (Analog pin shorts to ground). Please check your wiring and supply.");
            while (1)
                ;
        }
        // Save R0 to EEPROM
        EEPROM.put(EEPROM_ADDRESS_MQ136_R0, mq136_r0);
    }
    else
    {
        // Load R0 from EEPROM
        float mq136_r0 = 0.0;
        EEPROM.get(EEPROM_ADDRESS_MQ136_R0, mq136_r0);
        MQ136.setR0(mq136_r0);
    }
    MQ136.serialDebug(ENABLE_DEBUG_PRINTS);

    // Initialize MQ-137 Sensor
    MQ137.setRegressionMethod(1); // _PPM =  a*ratio^b
    MQ137.setA(A_VALUE_MQ137);
    MQ137.setB(B_VALUE_MQ137); // Configure the equation to calculate NH3 concentration

    MQ137.init();

    if (PERFORM_MQ_CALIBRATION)
    {
#if ENABLE_DEBUG_PRINTS
        Serial.print("Calibrating MQ-137, please wait.");
#endif
        float calcR0 = 0;
        for (int i = 1; i <= 10; i++)
        {
            MQ137.update(); // Read the voltage from the analog pin
            calcR0 += MQ137.calibrate(MQ137_RATIO_CLEAN_AIR);
#if ENABLE_DEBUG_PRINTS
            Serial.print(".");
#endif
        }
        float mq137_r0 = calcR0 / 10;
        MQ137.setR0(mq137_r0);
#if ENABLE_DEBUG_PRINTS
        Serial.println(" done!");
#endif

        if (isinf(calcR0))
        {
            Serial.println("Warning: Connection issue, MQ-137 R0 is infinite (Open circuit detected). Please check your wiring and supply.");
            while (1)
                ;
        }
        if (calcR0 == 0)
        {
            Serial.println("Warning: Connection issue found, MQ-137 R0 is zero (Analog pin shorts to ground). Please check your wiring and supply.");
            while (1)
                ;
        }
        // Save R0 to EEPROM
        EEPROM.put(EEPROM_ADDRESS_MQ137_R0, mq137_r0);
    }
    else
    {
        // Load R0 from EEPROM
        float mq137_r0 = 0.0;
        EEPROM.get(EEPROM_ADDRESS_MQ137_R0, mq137_r0);
        MQ137.setR0(mq137_r0);
    }
    MQ137.serialDebug(ENABLE_DEBUG_PRINTS);

    // Initialize MQ-9b Sensor
    MQ9B.setRegressionMethod(1); // _PPM =  a*ratio^b
    MQ9B.setA(A_VALUE_MQ9B_CH4); // Methane (CH4) model
    MQ9B.setB(B_VALUE_MQ9B_CH4); // Methane (CH4) model

    MQ9B.init();

    if (PERFORM_MQ_CALIBRATION)
    {
#if ENABLE_DEBUG_PRINTS
        Serial.print("Calibrating MQ-9b, please wait.");
#endif
        float calcR0 = 0;
        for (int i = 1; i <= 10; i++)
        {
            MQ9B.update(); // Read the voltage from the analog pin
            calcR0 += MQ9B.calibrate(MQ9B_RATIO_CLEAN_AIR);
#if ENABLE_DEBUG_PRINTS
            Serial.print(".");
#endif
        }
        float mq9b_r0 = calcR0 / 10;
        MQ9B.setR0(mq9b_r0);
#if ENABLE_DEBUG_PRINTS
        Serial.println(" done!");
#endif

        if (isinf(calcR0))
        {
            Serial.println("Warning: Connection issue, MQ-9b R0 is infinite (Open circuit detected). Please check your wiring and supply.");
            while (1)
                ;
        }
        if (calcR0 == 0)
        {
            Serial.println("Warning: Connection issue found, MQ-9b R0 is zero (Analog pin shorts to ground). Please check your wiring and supply.");
            while (1)
                ;
        }
        // Save R0 to EEPROM
        EEPROM.put(EEPROM_ADDRESS_MQ9B_R0, mq9b_r0);
    }
    else
    {
        // Load R0 from EEPROM
        float mq9b_r0 = 0.0;
        EEPROM.get(EEPROM_ADDRESS_MQ9B_R0, mq9b_r0);
        MQ9B.setR0(mq9b_r0);
    }
    MQ9B.serialDebug(ENABLE_DEBUG_PRINTS);

    // Initialize LCD
    lcd.init();
    lcd.backlight();
    lcd.clear();

    // Initialize LiquidMenu
    initializeLCDMenu();
    menu.init(); // Important: Initialize the menu after adding screens

    // Initialize Alarms
    initializeAlarms();

    // Set LED to green initially
    analogWrite(redPin, 0);
    analogWrite(greenPin, 255);
    analogWrite(bluePin, 0);

    // Initialize Relay for MQ-9b (Start in HIGH state - 5V)
    digitalWrite(relayPin, HIGH); // HIGH corresponds to 5V phase
    mq9bSwitchTime = millis();    // Initialize the switch time

#if ENABLE_DEBUG_PRINTS
    Serial.println(F("System initialized."));
#endif
}

void loop()
{
    unsigned long currentMillis = millis();

    // Handle button press continuously
    handleButtonPress();

    // Relay control for MQ-9b
    controlMQ9bRelay();

    // Only read sensors every `SAMPLING_INTERVAL_MS`
    if (currentMillis - lastMillis >= SAMPLING_INTERVAL_MS)
    {
        lastMillis = currentMillis; // Use currentMillis instead of millis()

        // Read sensors and update data
        readSensors();

        // Update LCD menu display
        updateLCDMenu();

        // Check and trigger alarms
        checkAndTriggerAlarms();

        // Log sensor data
        logSensorData();
    }

    // Handle alarm buzzer and LED colors based on alarmLevel
    if (alarmLevel == DANGER)
    {
        // Buzzer on continuously
        digitalWrite(buzzerPin, HIGH);

        // Set LED to red
        analogWrite(redPin, 255);
        analogWrite(greenPin, 0);
        analogWrite(bluePin, 0);
    }
    else if (alarmLevel == WARNING)
    {
        // Buzzer toggles on and off periodically
        if (currentMillis - lastBuzzerToggleTime >= BUZZER_TOGGLE_INTERVAL_MS)
        {
            buzzerState = !buzzerState;
            digitalWrite(buzzerPin, buzzerState ? HIGH : LOW);
            lastBuzzerToggleTime = currentMillis;
        }

        // Set LED to orange (mix of red and green)
        analogWrite(redPin, 255);
        analogWrite(greenPin, 165); // Approximate value for orange
        analogWrite(bluePin, 0);
    }
    else // NO_ALARM
    {
        // Buzzer off
        digitalWrite(buzzerPin, LOW);

        // Set LED to green
        analogWrite(redPin, 0);
        analogWrite(greenPin, 255);
        analogWrite(bluePin, 0);
    }
}

void initializePins()
{
    // RGB LED Pins
    pinMode(redPin, OUTPUT);
    pinMode(greenPin, OUTPUT);
    pinMode(bluePin, OUTPUT);

    // Buzzer Pin
    pinMode(buzzerPin, OUTPUT);

    // Button Pin
    pinMode(buttonPin, INPUT_PULLUP); // Assuming button connected to GND when pressed

    // Relay Pin for MQ-9b
    pinMode(relayPin, OUTPUT);

    // Ensure alarms and relay are in their initial states
    digitalWrite(buzzerPin, LOW);
    digitalWrite(relayPin, HIGH); // Start in HIGH (5V) position
    analogWrite(redPin, 0);
    analogWrite(greenPin, 0);
    analogWrite(bluePin, 0);
}

void initializeAlarms()
{
    // Alarms are already initialized in initializePins()
}

void initializeLCDMenu()
{
    // Set decimal places for floats and integers as needed
    screen0_line2.set_decimalPlaces(0);  // Timestamp is a string, no decimals
    screen1_line2.set_decimalPlaces(0);  // CO2 ppm
    screen2_line2.set_decimalPlaces(1);  // Temperature C
    screen3_line2.set_decimalPlaces(1);  // Humidity %RH
    screen4_line2.set_decimalPlaces(0);  // AQI
    screen5_line2.set_decimalPlaces(0);  // TVOC ppb
    screen6_line2.set_decimalPlaces(0);  // eCO2 ppm
    screen7_line2.set_decimalPlaces(2);  // H2 ppm
    screen8_line2.set_decimalPlaces(2);  // H2S ppm
    screen9_line2.set_decimalPlaces(2);  // NH3 ppm
    screen10_line2.set_decimalPlaces(2); // CH4 ppm
    screen11_line2.set_decimalPlaces(2); // CO ppm

    // Add screens to menu
    menu.add_screen(screen0);
    menu.add_screen(screen1);
    menu.add_screen(screen2);
    menu.add_screen(screen3);
    menu.add_screen(screen4);
    menu.add_screen(screen5);
    menu.add_screen(screen6);
    menu.add_screen(screen7);
    menu.add_screen(screen8);
    menu.add_screen(screen9);
    menu.add_screen(screen10);
    menu.add_screen(screen11);
}

void readSensors()
{
    if (!Rtc.IsDateTimeValid())
    {
#if ENABLE_DEBUG_PRINTS
        Serial.println(F("RTC lost confidence in the DateTime!"));
#endif
    }

    RtcDateTime now = Rtc.GetDateTime();

    // Update timestamp
    snprintf(timestamp, sizeof(timestamp), "%02u/%02u/%04u %02u:%02u:%02u",
             now.Month(), now.Day(), now.Year(),
             now.Hour(), now.Minute(), now.Second());

    // Read SCD41 sensor
    if (scd41.readMeasurement())
    {
        co2 = scd41.getCO2();
        temperature = scd41.getTemperature();
        humidity = scd41.getHumidity();
    }
    else
    {
#if ENABLE_DEBUG_PRINTS
        Serial.println(F("Failed to read from SCD41 sensor."));
#endif
    }

    // Read ENS160 sensor
    if (ens160.available())
    {
        ens160.set_envdata(temperature, humidity);
        ens160.measure(true);
        ens160.measureRaw(true);

        aqi = ens160.getAQI();
        tvoc = ens160.getTVOC();
        eco2 = ens160.geteCO2();
    }
    else
    {
#if ENABLE_DEBUG_PRINTS
        Serial.println(F("ENS160 not available."));
#endif
    }

    // Read MQ-8 Sensor
    MQ8.update();              // Read the voltage from the analog pin
    h2_ppm = MQ8.readSensor(); // Get the H2 concentration in ppm

    // Read MQ-136 Sensor
    MQ136.update();               // Read the voltage from the analog pin
    h2s_ppm = MQ136.readSensor(); // Get the H2S concentration in ppm

    // Read MQ-137 Sensor
    MQ137.update();               // Read the voltage from the analog pin
    nh3_ppm = MQ137.readSensor(); // Get the NH3 concentration in ppm

    // Read MQ-9b Sensor
    MQ9B.update(); // Read the voltage from the analog pin

    unsigned long currentMillis = millis();

    if (mq9bHighState)
    {
        // HIGH (5V) phase: measure CH4
        MQ9B.setA(A_VALUE_MQ9B_CH4);
        MQ9B.setB(B_VALUE_MQ9B_CH4);

        // Check if settling time has passed
        if (currentMillis - mq9bSwitchTime >= SETTLE_TIME_TO_CH4)
        {
            ch4_ppm = MQ9B.readSensor();
        }
        else
        {
            ch4_ppm = NAN;
        }
        co_ppm = NAN; // CO measurement is not valid in this phase
    }
    else
    {
        // LOW (1.5V) phase: measure CO
        MQ9B.setA(A_VALUE_MQ9B_CO);
        MQ9B.setB(B_VALUE_MQ9B_CO);

        // Check if settling time has passed
        if (currentMillis - mq9bSwitchTime >= SETTLE_TIME_TO_CO)
        {
            co_ppm = MQ9B.readSensor();
        }
        else
        {
            co_ppm = NAN;
        }
        ch4_ppm = NAN; // CH4 measurement is not valid in this phase
    }
}

void handleButtonPress()
{
    int reading = digitalRead(buttonPin);

    if (reading != lastButtonState)
    {
        lastDebounceTime = millis();
    }

    if ((millis() - lastDebounceTime) > DEBOUNCE_DELAY_MS)
    {
        if (reading != buttonState)
        {
            buttonState = reading;
            if (buttonState == LOW)
            { // Button pressed
                menu.next_screen();
                // LED color no longer changes on button press
            }
        }
    }

    lastButtonState = reading;
}
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

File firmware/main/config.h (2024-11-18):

#ifndef CONFIG_H
#define CONFIG_H

#include <Arduino.h> // Ensure Arduino definitions are available

// ------------------------------
// Debugging Settings
// ------------------------------
#define ENABLE_DEBUG_PRINTS false  // Enable/Disable debug prints
#define ENABLE_DATA_PRINTS true   // Enable/Disable data readings

// ------------------------------
// Calibration Settings
// ------------------------------
#define PERFORM_MQ_CALIBRATION false // Set to true to perform calibration of MQ sensors

// ------------------------------
// Logging Settings
// ------------------------------
#define LOG_FILE_NAME "dataLog3.csv" // Name of the log file on SD card (changed to .csv)
#define LOG_TO_SD true              // Enable/Disable logging to SD card

// ------------------------------
// Pin Definitions
// ------------------------------
const int redPin = 3;     // Digital Pin D3 for Red LED
const int greenPin = 5;   // Digital Pin D5 for Green LED
const int bluePin = 6;    // Digital Pin D6 for Blue LED
const int buzzerPin = 7;  // Digital Pin D7 for Piezo Buzzer
const int buttonPin = A6; // Analog Pin A6 for Push Button

const int mq8Pin = A0;     // Analog Pin A0 for MQ-8 Sensor (H₂)
const int mq136Pin = A1;   // Analog Pin A1 for MQ-136 Sensor (H₂S)
const int mq137Pin = A2;   // Analog Pin A2 for MQ-137 Sensor (NH₃)
const int mq9bPin = A3;    // Analog Pin A3 for MQ-9b Sensor (CO & CH₄)
const int relayPin = 4;    // Digital Pin 4 for Relay Control (MQ-9b Heater Voltage)

// RTC Chip Select Pin
const uint8_t DS3234_CS_PIN = 10; // DS3234 Chip-select pin

// SD Card Chip Select Pin
const uint8_t chipSelect = 8; // SD card CS pin

// ------------------------------
// Standard Colors Definitions
// ------------------------------
const int RED[3]     = {255, 0, 0};
const int GREEN[3]   = {0, 255, 0};

// ------------------------------
// Sampling Settings
// ------------------------------
#define SAMPLING_INTERVAL_MS 5000 // Interval between sensor readings in milliseconds (5 seconds)

// ------------------------------
// I2C LCD Settings
// ------------------------------
#define LCD_I2C_ADDRESS 0x27 // I2C address of the LCD
#define LCD_COLUMNS 16       // Number of columns on the LCD
#define LCD_ROWS 2           // Number of rows on the LCD

// ------------------------------
// Serial Communication Settings
// ------------------------------
#define SERIAL_BAUD_RATE 115200 // Baud rate for serial communication

// ------------------------------
// Debounce Settings
// ------------------------------
#define DEBOUNCE_DELAY_MS 50 // Debounce delay in milliseconds

#endif // CONFIG_H

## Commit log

2024-11-02 completed schematic, protoboard implementation, software check of individual components using example scripts and did 3 iterations of the 3d printed case
2024-11-03 finished schematic and implemented
    [environmental_safety_logger.kicad_sch]
2024-11-04 initial working prototype of code
2024-11-04 some docs and organization
    [hardware.kicad_pcb, hardware.kicad_sch]
2024-11-06 added pin defs for mq
2024-11-06 added in mq-8 gas sensor, just need to add other 3 now
2024-11-06 added other three mq sensors to finish out all sensors, changed LED to be tied to alarm, general finalizing of items
2024-11-07 removed readme printouts
2024-11-08 added BOM
    [BOM_v0.ods]
2024-11-08 added resulting data and python analysis
    [DATALOG_11072024.csv]
2024-11-18 added newData using updated a and b regression values
    [DATALOG.CSV, DATALOG1.CSV, DATALOG2.CSV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]
